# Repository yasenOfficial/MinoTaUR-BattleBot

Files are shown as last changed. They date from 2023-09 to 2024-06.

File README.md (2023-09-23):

# MinoTaUR-BattleBot

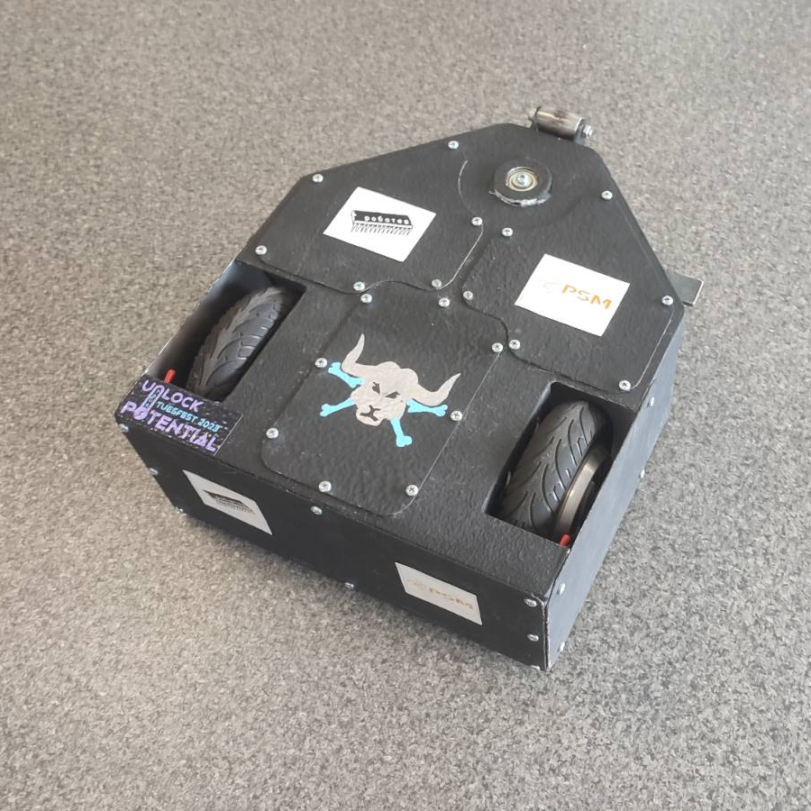
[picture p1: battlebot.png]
battlebot


# Introduction
This battle-ready machine is constructed from durable stainless steel, powered by repurposed hoverboard motors, and controlled by an Arduino-based system and a 2.4 GHz receiver . It has proven its worth on the BattleBots arena and is ready for more action.

# Features
Stainless Steel Build: The BattleBot is constructed from high-quality stainless steel, providing exceptional durability, resistance to damage during combat and making it 25 kilograms.

Hoverboard Motors: The bot is driven by motors salvaged from a disassembled hoverboard, delivering powerful and agile movement on the battlefield. These Motors can carry about 100 kilograms! When the robot is started and the speed is at max the front part of the battlebot lifts up about 6 degrees.

Arduino Control: An Arduino-based control system manages the BattleBot's weapon control. It reads the signals from the 2.4GHz receiver and based on the timing of the impulses decides whether to turn on the fast spinning metal blade.

High-Speed Spinning Blade: The BattleBot is equipped with a high-speed spinning blade that can cause significant damage to opponents. The motor that spins this blade is from a disassembled drill. 

2.4GHz Receiver: The bot communicates with its operator using a 2.4GHz receiver, ensuring reliable control during intense battles.

Hoverboard motherboard: We salvaged the motherboard from the hoverboard and reflashed its firmware ( that way the motors can go faster only by changing the software ). The new software also allows us to connect the 2.4 Ghz receiver directly to the motherboard.

Champion of TUES BattleBots 2023: This BattleBot has already proven its mettle by winning the prestigious TUES BattleBots competition in 2023.

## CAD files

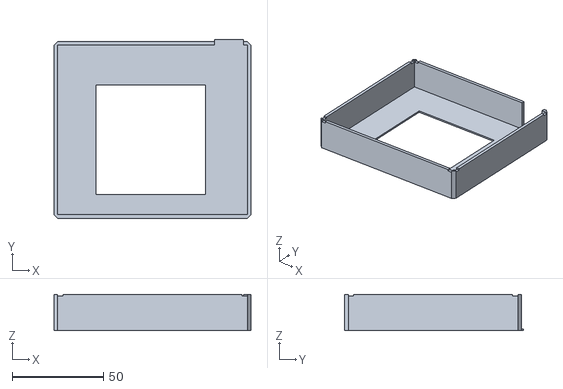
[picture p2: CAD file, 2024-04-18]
STLs/BattleBotRemoteBottom.stl
108.0 x 98.0 x 20.0

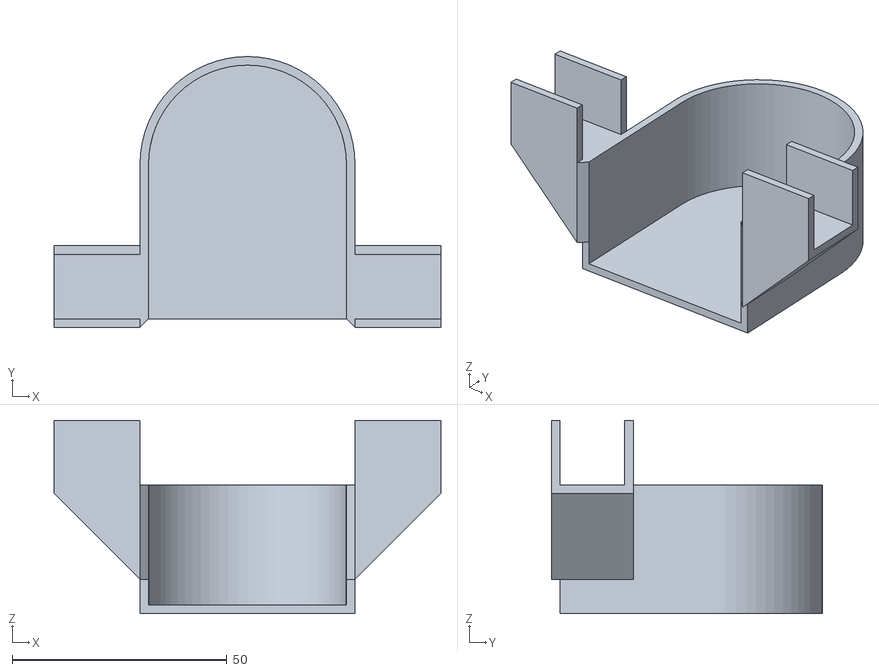
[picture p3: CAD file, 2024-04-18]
STLs/BattleBotSpinerGuard.stl
90.0 x 63.0 x 45.0

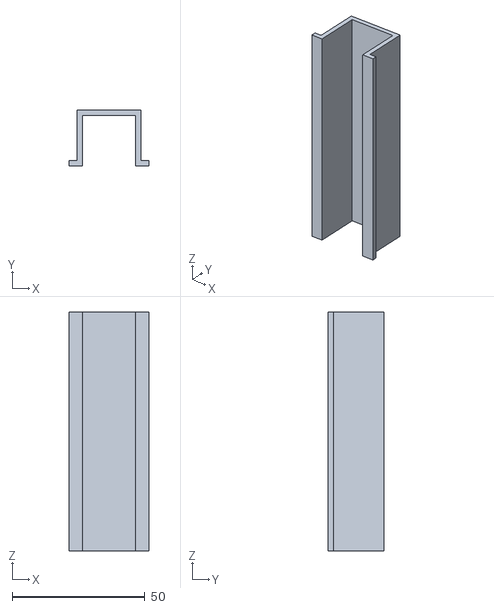
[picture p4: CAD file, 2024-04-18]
STLs/BattleBotRemoteBatteryHolder.stl
30.0 x 21.0 x 90.0

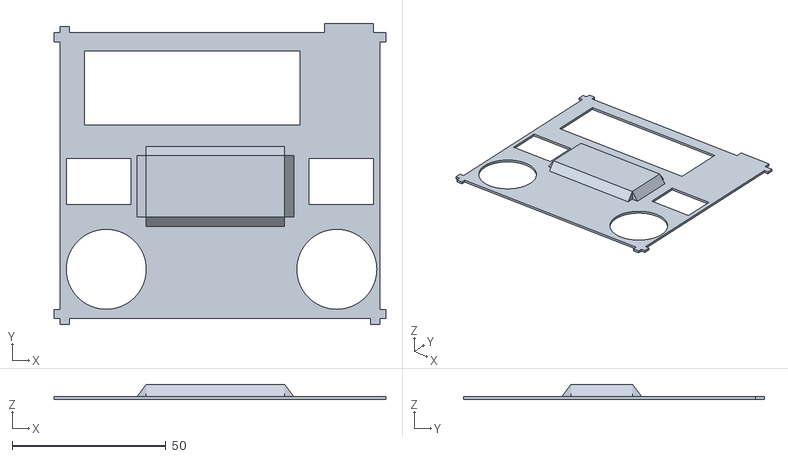
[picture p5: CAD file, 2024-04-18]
STLs/BattleBotRemoteTop.stl
108.0 x 98.0 x 5.00

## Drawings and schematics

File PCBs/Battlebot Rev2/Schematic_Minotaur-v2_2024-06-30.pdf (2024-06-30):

# D26 24 D25 23 D33 22 D32 21 D35 20 D34 19 VN 18 VP 17 EN 16

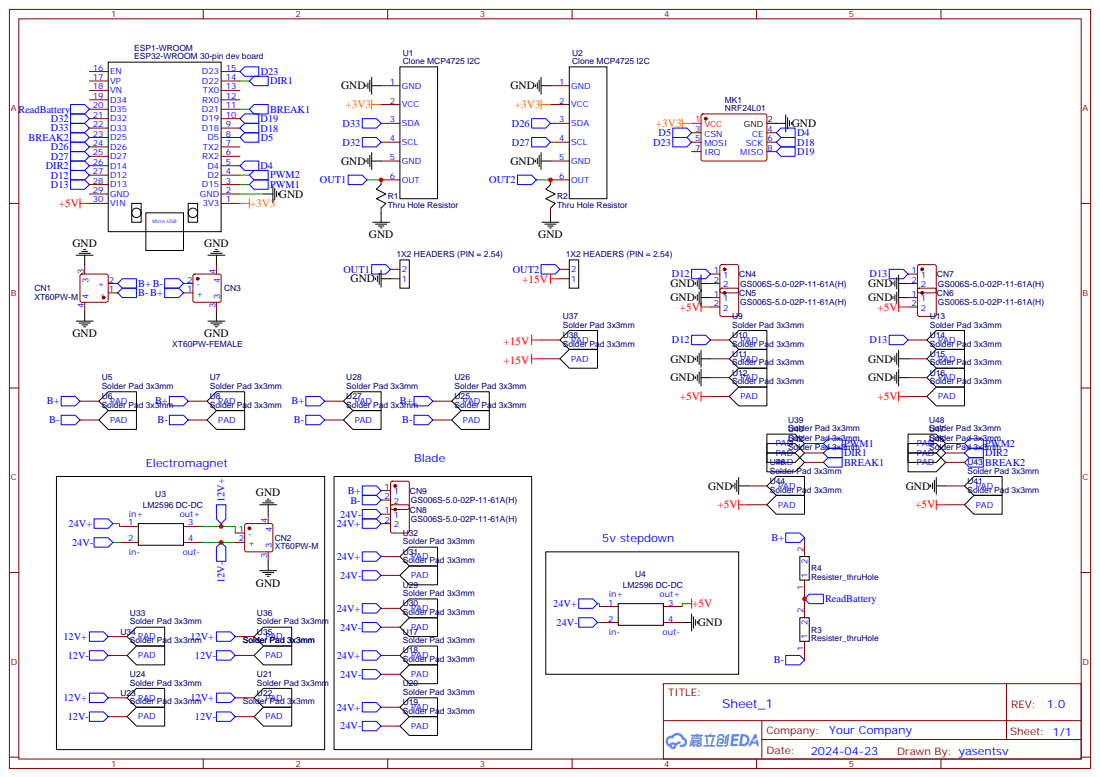
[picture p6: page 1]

ESP1-WROOM
ESP32-WROOM 30-pin dev board

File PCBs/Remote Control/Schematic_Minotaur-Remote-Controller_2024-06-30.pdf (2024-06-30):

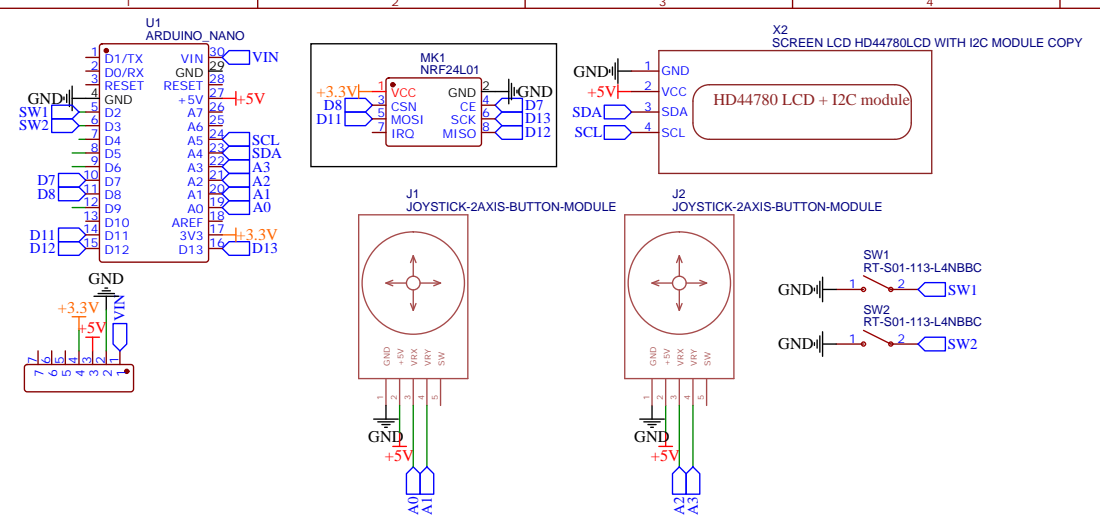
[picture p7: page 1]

SCREEN LCD HD44780LCD WITH I2C MODULE COPY

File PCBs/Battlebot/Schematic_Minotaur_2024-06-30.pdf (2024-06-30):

## MPU

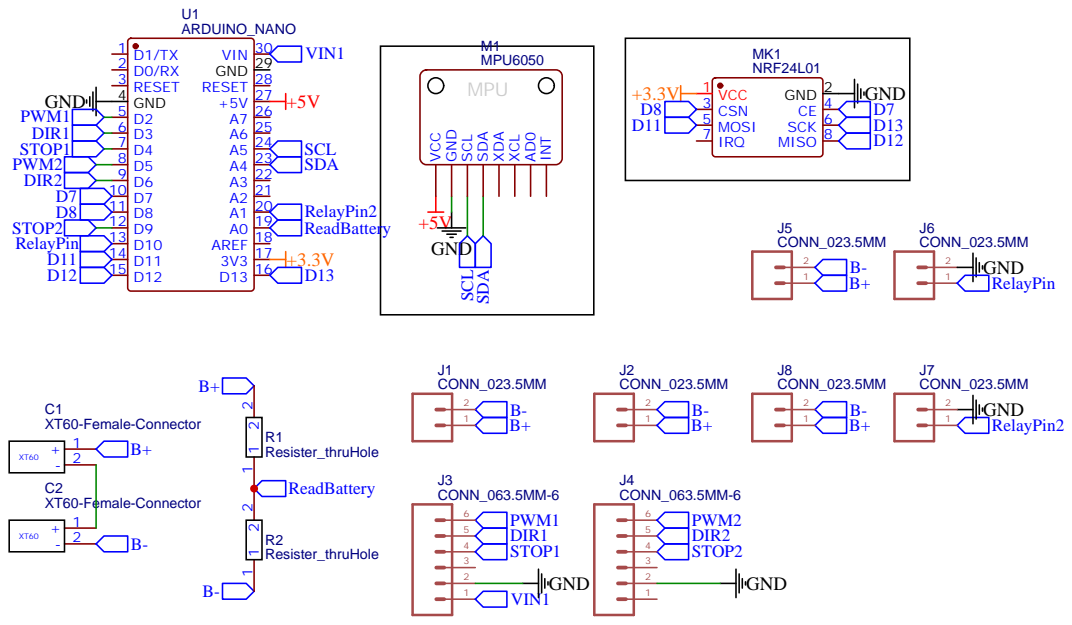
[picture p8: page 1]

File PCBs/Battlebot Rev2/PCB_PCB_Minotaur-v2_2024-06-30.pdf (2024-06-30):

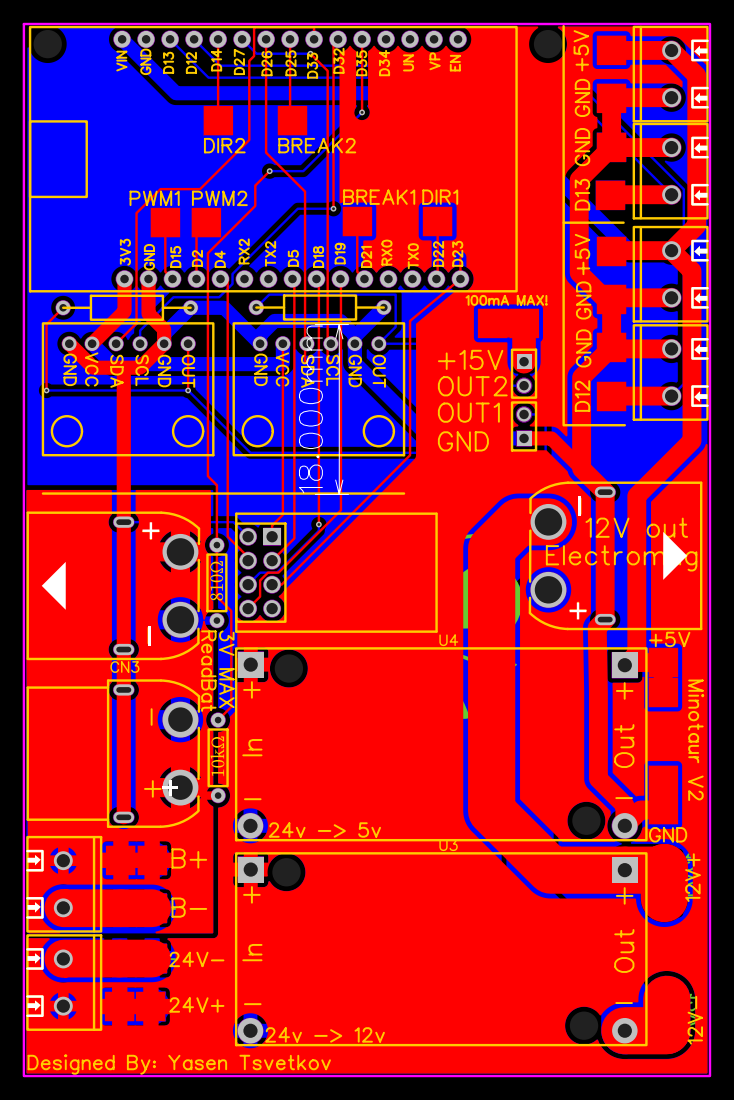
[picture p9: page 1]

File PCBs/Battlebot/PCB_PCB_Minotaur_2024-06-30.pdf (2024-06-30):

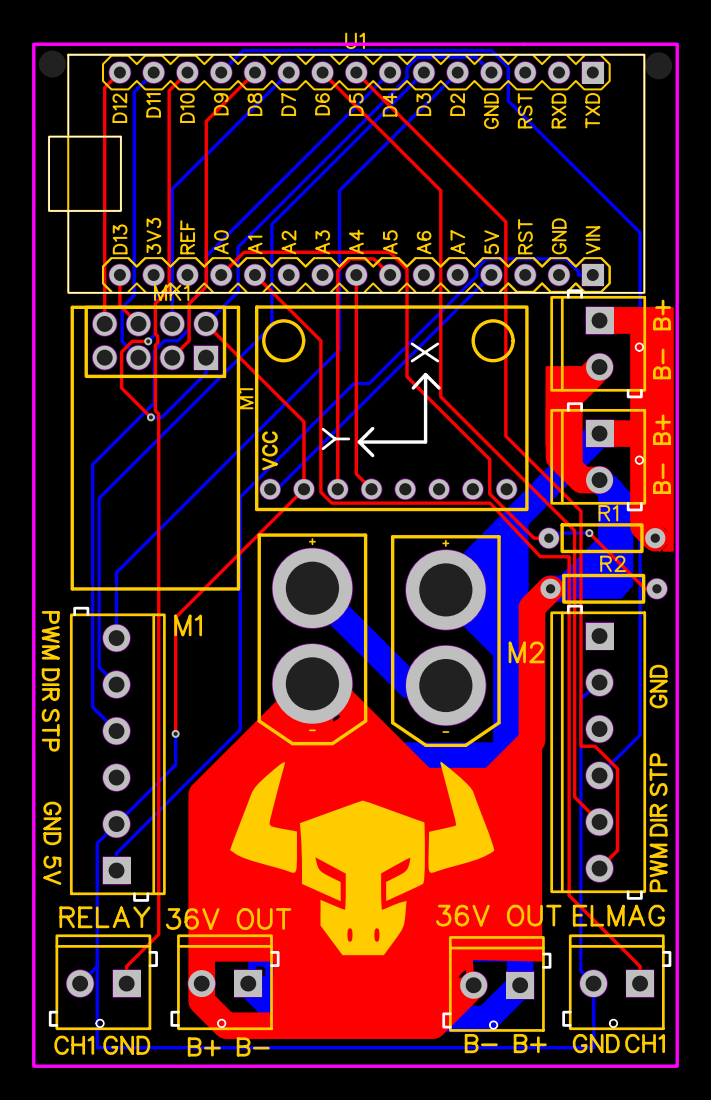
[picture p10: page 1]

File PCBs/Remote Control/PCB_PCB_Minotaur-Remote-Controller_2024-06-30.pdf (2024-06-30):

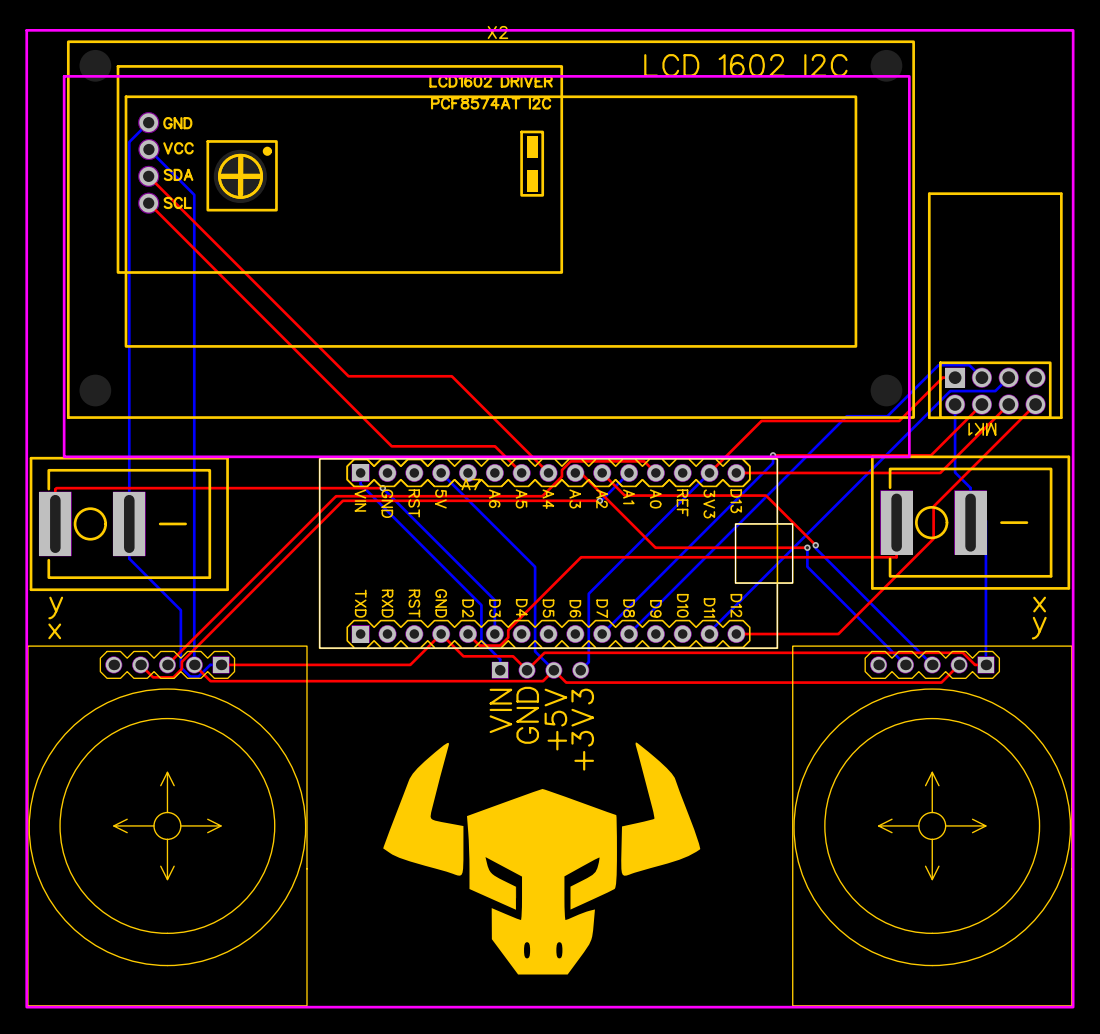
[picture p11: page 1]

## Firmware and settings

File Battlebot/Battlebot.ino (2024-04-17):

#include <SPI.h>
#include <nRF24L01.h>
#include <RF24.h>

#include <Adafruit_MPU6050.h>
#include <Adafruit_Sensor.h>
#include <Wire.h>

#define rellayPin 10
#define rellayPinMagnet A1

#define motor1Pin 2
#define direction_pin1 3
#define stop_pin1 4

#define motor2Pin 5
#define direction_pin2 6
#define stop_pin2 9

RF24 radio(7, 8); // CE, CSN

Adafruit_MPU6050 mpu;

const byte address[6] = "00001";

void setup() {
  pinMode(direction_pin1, OUTPUT);
  pinMode(stop_pin1, OUTPUT);
  pinMode(direction_pin2, OUTPUT);
  pinMode(stop_pin2, OUTPUT);
  pinMode(rellayPin, OUTPUT);
  pinMode(rellayPinMagnet, OUTPUT);

  Serial.begin(9600);

  radio.begin();
  radio.openReadingPipe(1, address);
  radio.setPALevel(RF24_PA_MIN);
  radio.startListening();

  if (!mpu.begin()) {
		Serial.println("Failed to find MPU6050 chip");
		while (1) {
		  delay(10);
		}
	}

  mpu.setAccelerometerRange(MPU6050_RANGE_8_G);

	// set gyro range to +- 500 deg/s
	mpu.setGyroRange(MPU6050_RANGE_500_DEG);

	// set filter bandwidth to 21 Hz
	mpu.setFilterBandwidth(MPU6050_BAND_21_HZ);
}

// Structure to store received data
struct {
  int joy1X;
  int joy1Y;
  int joy2X;
  int joy2Y;
  bool rellayController;
  bool rellayControllerPinMagnet;
}receivedData;

struct {
  int batteryLevel;
  float speed;
  bool isFlipped;
}dataToSend;

int motor1Dir = 0;
int motor2Dir = 0;

void loop() {
  if (radio.available()) {
    radio.read(&receivedData, sizeof(receivedData));
    
    // Map the joystick X values from the range 0-1023 to the range 0-255
    // int mappedJoy1X = map(receivedData.joy1X, 0, 1023, 0, 255);
    // int mappedJoy2X = map(receivedData.joy2X, 0, 1023, 0, 255);
    Serial.println(receivedData.joy1X);    
    // Control Motor 1 based on joystick 1 input
    if (receivedData.joy1X <= 200) {
      if(motor1Dir < 1){
        digitalWrite(stop_pin1, LOW);
        motor1Dir = 1;
      }else{
        int mappedJoy1X = map(receivedData.joy1X, 320, 0, 0, 255);
        digitalWrite(stop_pin1, HIGH);
        digitalWrite(direction_pin1, LOW);
        analogWrite(motor1Pin, mappedJoy1X);
        }
    } else if (receivedData.joy1X >= 820 ) {
      if(motor1Dir > -1){
        digitalWrite(stop_pin1, LOW);
        motor1Dir = -1;
      }else{
        int mappedJoy1X = map(receivedData.joy1X, 700, 1023, 0, 255);
        digitalWrite(stop_pin1, HIGH);
        digitalWrite(direction_pin1, HIGH);
        analogWrite(motor1Pin, mappedJoy1X);
        }
    } else {
        digitalWrite(stop_pin1, LOW);
    }
    
    // Control Motor 2 based on joystick 2 input
    if (receivedData.joy2X <= 200) {
      if(motor2Dir < 1){
        digitalWrite(stop_pin2, LOW);
        motor2Dir = 1;
      }else{
        int mappedJoy2X = map(receivedData.joy2X, 320, 0, 0, 255);
        digitalWrite(stop_pin2, HIGH);
        digitalWrite(direction_pin2, LOW);
        analogWrite(motor2Pin, mappedJoy2X);
        }
    } else if (receivedData.joy2X >= 820) {
        if(motor2Dir > -1){
          digitalWrite(stop_pin2, LOW);
          motor2Dir = -1;
        }else{
        int mappedJoy2X = map(receivedData.joy2X, 700, 1023, 0, 255);
        digitalWrite(stop_pin2, HIGH);
        digitalWrite(direction_pin2, HIGH);
        analogWrite(motor2Pin, mappedJoy2X);
        }
    } else {
        digitalWrite(stop_pin2, LOW);
    }
    
    // Control relay based on relay controller input
    digitalWrite(rellayPin, receivedData.rellayController);
    digitalWrite(rellayPinMagnet, receivedData.rellayControllerPinMagnet);
    
}

  sensors_event_t a, g, t;
	mpu.getEvent(&a, &g, &t);

  dataToSend.batteryLevel = 100;
  dataToSend.isFlipped = g.gyro.y;
  dataToSend.speed = a.acceleration.x;

  delay(10);

  radio.stopListening();

  radio.openWritingPipe(address);
  radio.write(&dataToSend, sizeof(dataToSend));
  radio.openReadingPipe(1, address);
  radio.startListening();
}

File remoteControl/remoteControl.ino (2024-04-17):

#include <SPI.h>
#include <nRF24L01.h>
#include <RF24.h>
#include <LiquidCrystal_I2C.h>
#include <Wire.h>

RF24 radio(7, 8); // CE, CSN

const byte address[6] = "00001";

const int joy1XPin = A0;  // X-axis pin
const int joy1YPin = A1;  // Y-axis pin
const int joy2XPin = A2;  // X-axis pin
const int joy2YPin = A3;  // Y-axis pin
const int rellayControllerPin = 3;
const int rellayControllerPinMagnet = 2;

LiquidCrystal_I2C lcd(0x27,  16, 2);

void setup() {
  pinMode(rellayControllerPin, INPUT_PULLUP);
  pinMode(rellayControllerPinMagnet, INPUT_PULLUP);
  Serial.begin(9600);
  radio.begin();
  radio.openReadingPipe(1, address);
  radio.setPALevel(RF24_PA_MIN);
  radio.startListening();

  lcd.init();
  lcd.backlight();
}

struct {
  int joy1X;
  int joy1Y;
  int joy2X;
  int joy2Y;
  bool rellayController;
  bool rellayControllerPinMagnet;
}dataToSend;

struct {
  int batteryLevel;
  float speed;
  bool isFlipped;
}receivedData;

void loop() {
    Serial.println("-----");

  if (radio.available()) {
    while (radio.available()){
      radio.read( &receivedData, sizeof(receivedData) );
    }
    Serial.println("Recieve: ");
    Serial.print("Package:");
    Serial.print(receivedData.batteryLevel);
    Serial.print("\n");
    Serial.println(receivedData.speed);
    Serial.println(receivedData.isFlipped);
    Serial.print("\n");
  }

  // Read analog values from X and Y axes
  int joy1XValue = analogRead(joy1XPin);
  int joy1YValue = analogRead(joy1YPin);

  int joy2XValue = analogRead(joy2XPin);
  int joy2YValue = analogRead(joy2YPin);
  //Serial.println(joyXValue);

  dataToSend.joy1X = joy1XValue;
  dataToSend.joy1Y = joy1YValue;
  dataToSend.joy2X = joy2XValue;
  dataToSend.joy2Y = joy2YValue;
  dataToSend.rellayController = !digitalRead(rellayControllerPin); 
  dataToSend.rellayControllerPinMagnet = !digitalRead(rellayControllerPinMagnet); 

  delay(10);

  radio.stopListening();
  radio.openWritingPipe(address);
  radio.write(&dataToSend, sizeof(dataToSend));
  radio.openReadingPipe(1, address);
  radio.startListening();

  lcd.setCursor(0,0);
  lcd.print("Battery: ");
  lcd.print(receivedData.batteryLevel);
  lcd.print("%");
  lcd.setCursor(0,1);
  lcd.print("Sped: ");
  lcd.print(receivedData.speed);
}

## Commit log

2024-04-17 add pcbs
2024-04-18 Added 3d models for the remote and guard
    [BattleBotRemoteBatteryHolder.stl, BattleBotRemoteBottom.stl, BattleBotRemoteTop.stl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]
2024-06-30 add viewable pcb pdfs and add v2
    [BattleBotRemoteBatteryHolder.stl, BattleBotRemoteBottom.stl, BattleBotRemoteTop.stl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]
